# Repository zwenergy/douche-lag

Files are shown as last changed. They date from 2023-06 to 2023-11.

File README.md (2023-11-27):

# douche lag
A modular lag testing device.
Still very much in the works right now.

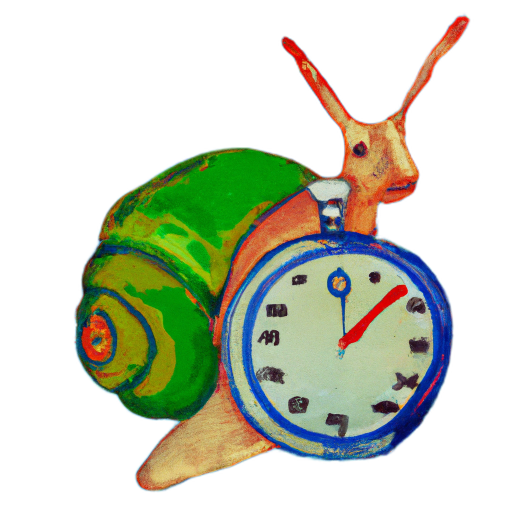
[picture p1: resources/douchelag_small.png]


*Amazingly cool and fancy logo of douche lag while keeping it SFW*

## Idea
The idea of douche lag is to have a simple and cheap, yet modular lag testing device to test the complete "lag chain" of a gaming system.
By "complete lag chain" I mean the time between button input and visual change on the screen.
Douche lag is doing that by emulating a button press and waiting for a visual change on screen.

The main idea is to be modular, that's why the project is split into 3 parts: The main board (containing the Raspberry Pi Pico and display), the "sense board" (which senses the visual change on the screen) and the "gamepad press emulation" (the part which actually emulates the button press).
The parts are connected using Mini DIN 6 cables/connectors.
The idea to keep it modular is to accomadate future updates.
Right now, it only supports displays which are back- or frontlit (since the sense board relies on a phototransistor) and gamepads which use a simple "commong ground switching" scheme.
To adapt this project to also non-lit displays, one could design a "sense board" with a color sensor.
Or more complex gamepads by designing a corresponding "gamepad daughter board".
Ideally, this potential future additions would not need a complete re-design, but only new daughter boards and a FW update.

## Test ROMs
Douche lag needs a program for each system to be tested which essentially toggles the display measurable by a button press.
Right now, there are ROMs for the following systems:
- GBA
- N64
- Genesis / Master Drive
- Saturn
- SNES
- NES

## Gamepad Modification
Right now, only gamepads which use a "common ground switching" scheme are supported (meaning a button press will cause the button input to be tied to ground).
For this, it's required to connect the ground connection of the "PAD" connector to the gamepad's ground, and "PAD1" to the button causing the display toggle.
This can be done in different ways:
- Permanently modify gamepad by adding a Mini DIN 6 connector
- Creating a "probing" cable with, e.g., multimeter probing heads on one side and a Mini DIN 6 connector on the other side
- Whatever you can think of

## BOM
### Main board
| **Reference** | **Part** | **Link** |
|---|---|---|
| U6 | Raspberry Pi Pico | [Digikey](https://www.digikey.com/en/products/detail/raspberry-pi/SC0915/13624793)|
| R1, R2 | 10k Ohm resistor 0805 | [LCSC](https://www.lcsc.com/product-detail/Chip-Resistor-Surface-Mount_UNI-ROYAL-Uniroyal-Elec-0805W8F1002T5E_C17414.html)|
| SW1, SW2 | Tactile switch | [LCSC](https://www.lcsc.com/product-detail/Tactile-Switches_BZCN-TSB008A2518A_C2888455.html)|
| PS1, PS2 | Mini DIN 6 connector | [LCSC](https://www.lcsc.com/product-detail/Circular-Connectors-Cable-Connectors_CONNFLY-Elec-DS1093-01-PN60_C77848.html)|
| PCB1 | 128x64 OLED display | [AliExpress](https://de.aliexpress.com/item/1005004242677199.html)|

**Make sure to get a display with the correct pinout order (VCC, GND, SCL, SDA) when looking from the top**

### Simple light sense board
| **Reference** | **Part** | **Link** |
|---|---|---|
| R1 | 1 kOhm resistor 1206 | [LCSC](https://www.lcsc.com/product-detail/Chip-Resistor-Surface-Mount_UNI-ROYAL-Uniroyal-Elec-1206W4F1001T5E_C4410.html)|
| R3 | 100 kOhm resistor 1206 | [LCSC](https://www.lcsc.com/product-detail/Chip-Resistor-Surface-Mount_UNI-ROYAL-Uniroyal-Elec-1206W4F1003T5E_C17900.html)|
| IR1 | Phototransistor 1206 | [LCSC](https://www.lcsc.com/product-detail/Phototransistors_Everlight-Elec-PT11-21C-L41-TR8_C16746.html)|
| Q1 | 2N7002 NMOS-FET SOT-23 | [LCSC](https://www.lcsc.com/product-detail/MOSFETs_Jiangsu-Changjing-Electronics-Technology-Co-Ltd-2N7002_C8545.html)|
| PS1 | Mini DIN 6 connector | [LCSC](https://www.lcsc.com/product-detail/Circular-Connectors-Cable-Connectors_CONNFLY-Elec-DS1093-01-PN60_C77848.html)|

## Usage
The main board simulates periodically a button press and meaures the time between this button press and the change on screen.
The button press is "emitted" via the Mini DIN 6 connector labelled "PAD".
Right now, effectively only two wires are used here to simulate a button press: ground and "PAD1".
This is enough for gamepads which use a "common ground switching scheme".

## Pinout Main Board to Gamepad Board
The following image shows a Mini DIN 6 connector (female, the one main board).

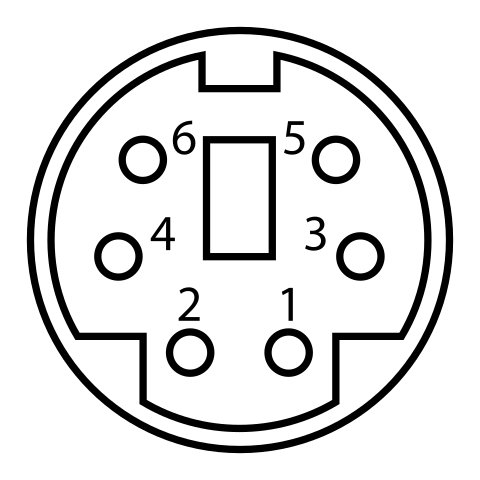
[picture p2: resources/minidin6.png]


| **Mini DIN 6 Pin** | **PAD Name** |
|---|---|
| 1 | Ground |
| 2 | PAD1 |
| 3 | PAD2|
| 4 | PAD3|
| 5 | PAD4|
| 6 | PAD5|

Right now, none of the PAD connection beside Ground and PAD1 connections are used.

## Disclaimer
**Use the files and/or schematics to build your own device at your own risk**.
This project works fine for me, but it's a simple hobby project, so there is no liability for errors in the schematics and/or board files.
**Use at your own risk**.

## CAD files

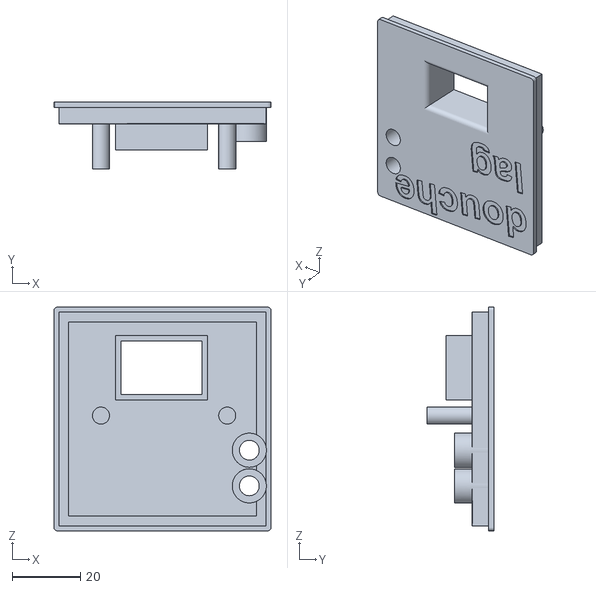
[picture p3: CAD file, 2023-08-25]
STL/main_case_top.stl
63.6 x 19.6 x 65.6

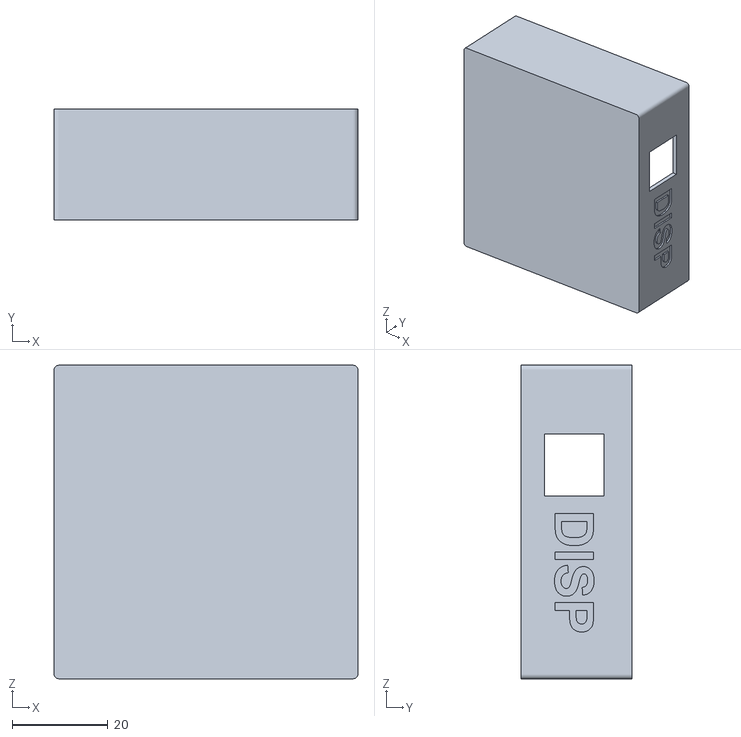
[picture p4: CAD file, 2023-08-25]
STL/main_case_body.stl
63.6 x 23.3 x 65.6

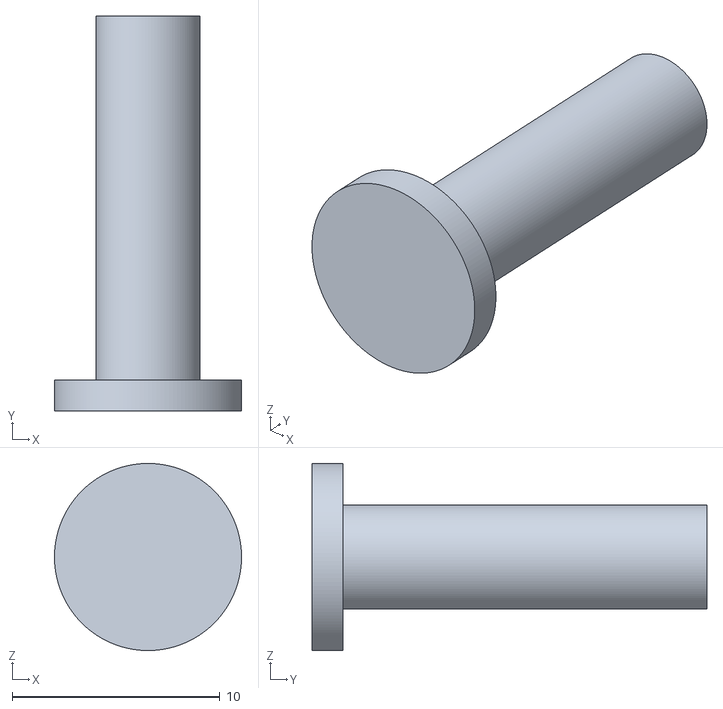
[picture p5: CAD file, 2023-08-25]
STL/main_case_button.stl
9.00 x 19.0 x 9.00

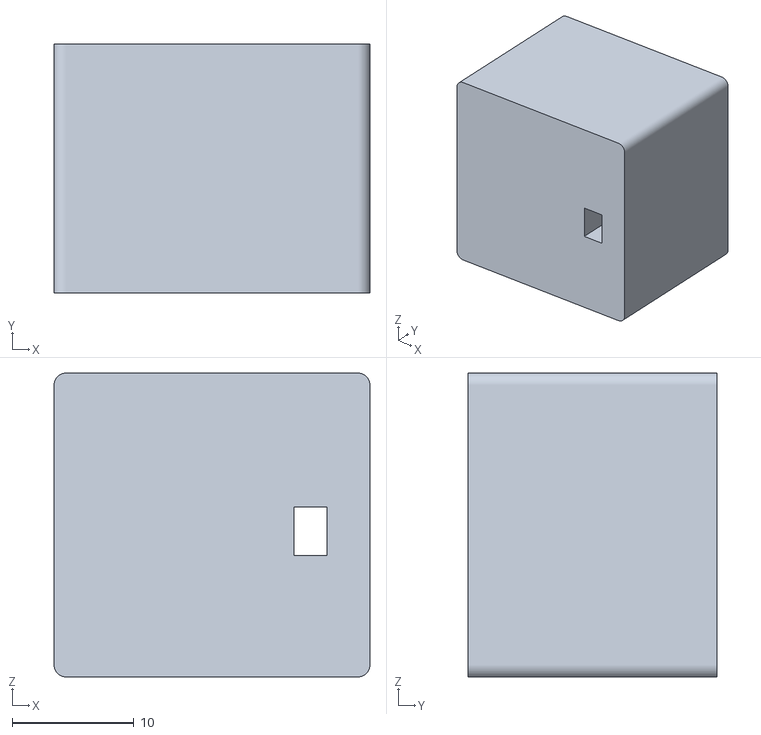
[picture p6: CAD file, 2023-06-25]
STL/senseboard_case_body.stl
26.0 x 20.5 x 25.0

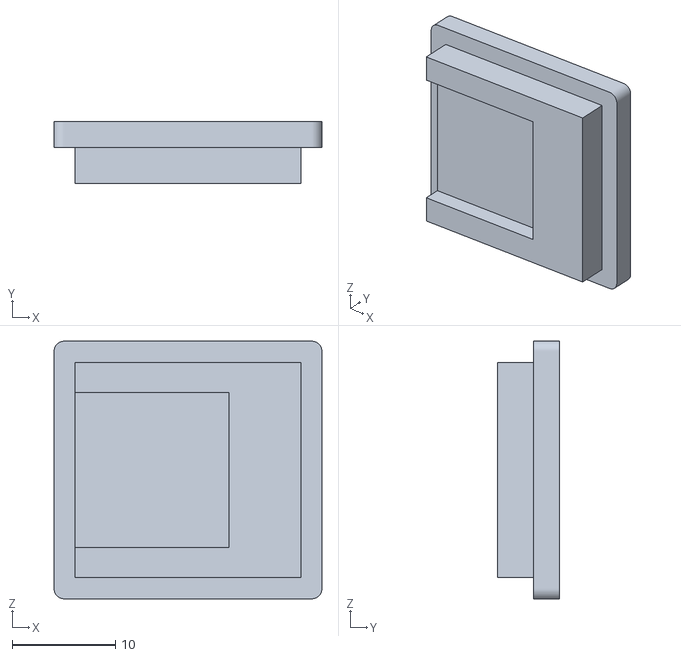
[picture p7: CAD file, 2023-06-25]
STL/senseboard_case_top.stl
26.0 x 6.00 x 25.0

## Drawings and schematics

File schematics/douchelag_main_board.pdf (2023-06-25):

A | A

1

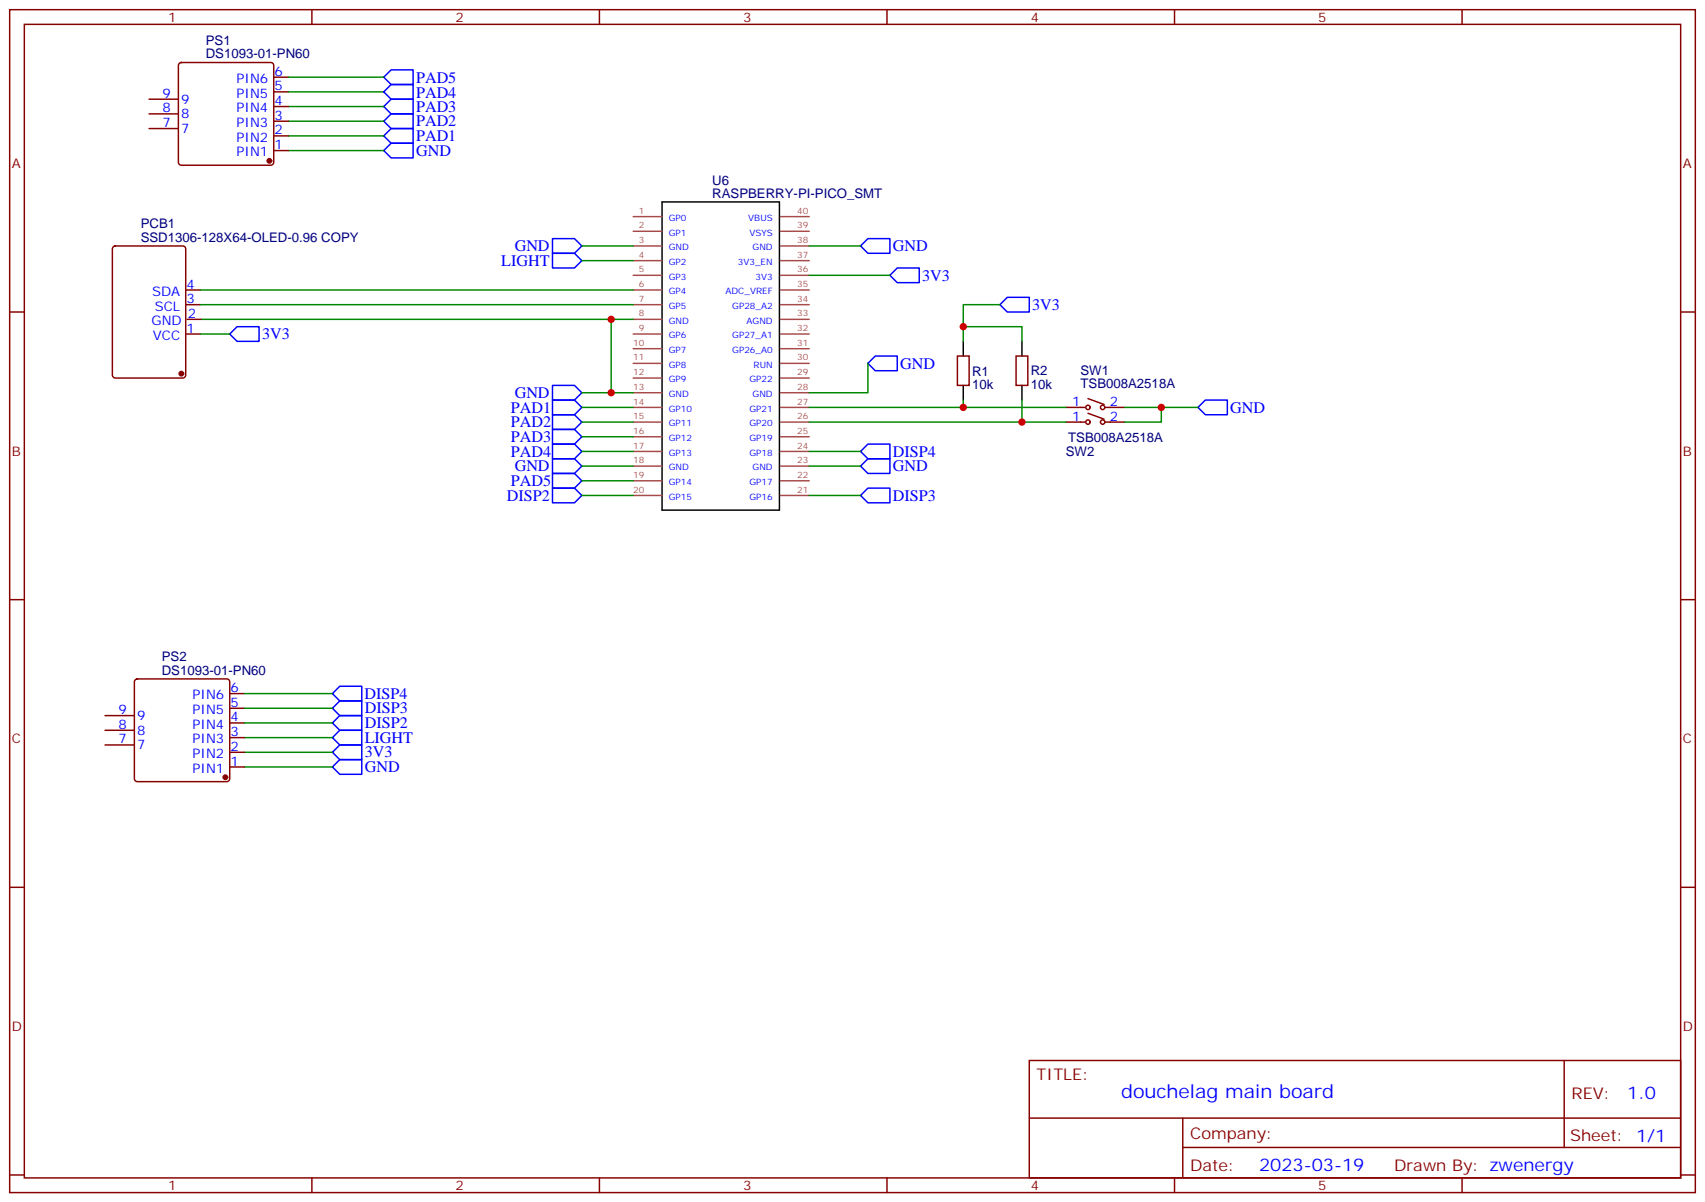
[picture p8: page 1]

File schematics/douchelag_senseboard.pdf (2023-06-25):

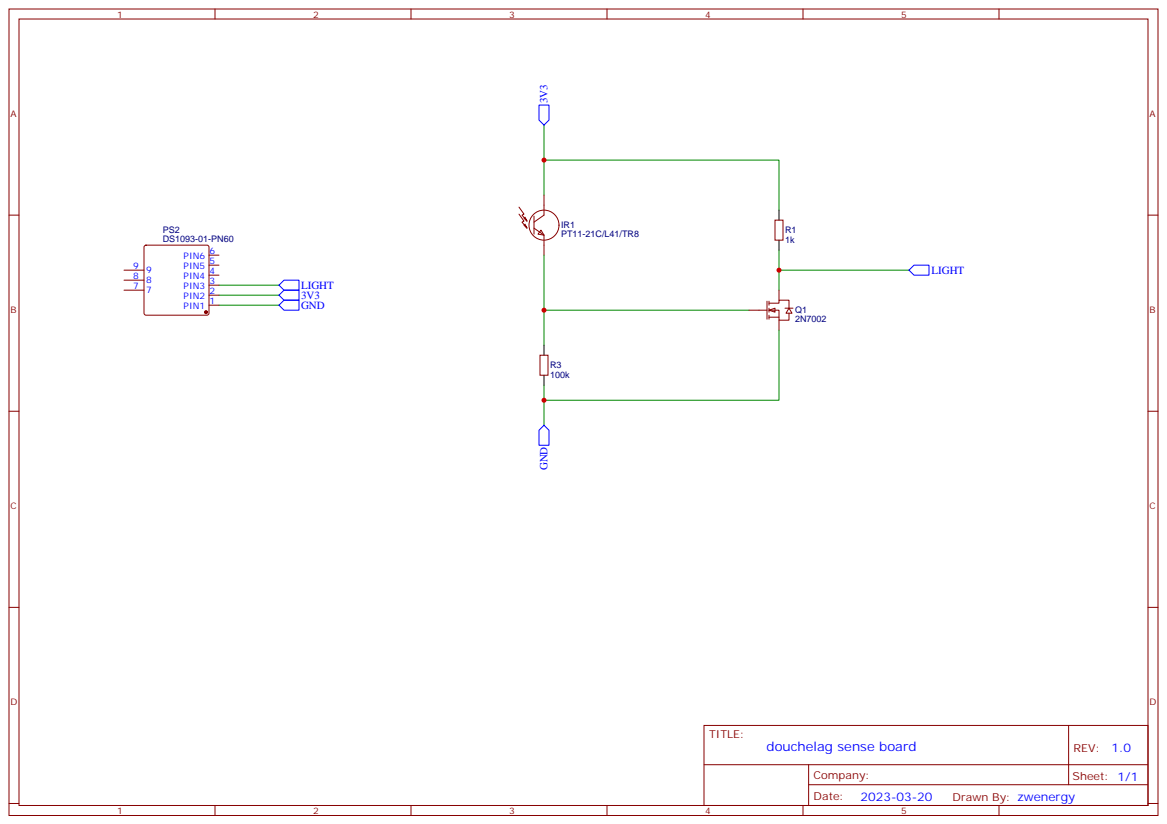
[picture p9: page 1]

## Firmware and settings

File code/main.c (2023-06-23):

#include <stdio.h>
#include <stdint.h>
#include <string.h>
#include "pico/stdlib.h"
#include "hardware/i2c.h"
#include <time.h>

#include "ssd1306.h"

#define I2C_SDA 4
#define I2C_CLK 5

#define LIGHTSENSE 2
#define PAD1 10
#define PAD2 11
#define PAD3 12
#define BTN1 21
#define BTN2 20

#define SCREENUS 500000
#define TOGGLEUS 60000
#define MAXSCREENDELAYUS SCREENUS / 2

// Number of readings per batch
#define BATCHSIZE 20

void setupGPIO() {
  stdio_init_all();
  
  // Display pins
  i2c_init(i2c0, 400000);
  gpio_set_function(I2C_SDA, GPIO_FUNC_I2C);
  gpio_set_function(I2C_CLK, GPIO_FUNC_I2C);
  gpio_pull_up(I2C_SDA);
  gpio_pull_up(I2C_CLK);
  
  // Light pin
  gpio_init(LIGHTSENSE);
  gpio_set_dir(LIGHTSENSE, GPIO_IN);
  //gpio_pull_up( LIGHTSENSE );
  
  // Buttons.
  gpio_init(BTN1);
  gpio_set_dir(BTN1, GPIO_IN);
  gpio_init(BTN2);
  gpio_set_dir(BTN2, GPIO_IN);
  
  // Pad, for the first set to input.
  gpio_init(PAD1);
  gpio_set_dir(PAD1, GPIO_IN);
  gpio_init(PAD2);
  gpio_set_dir(PAD2, GPIO_IN);
  gpio_init(PAD3);
  gpio_set_dir(PAD3, GPIO_IN);
  
}

int main() {
  stdio_init_all();
  setupGPIO();
  
  printf( "Starting\n" );
  
  // Set up display.
  ssd1306_t disp;
  disp.external_vcc = false;
  ssd1306_init( &disp, 128, 64, 0x3C, i2c0 );
  ssd1306_clear( &disp );
  
  // For GBA, set the output register value to low.
  gpio_put( PAD1, 0 );
  //gpio_pull_up( PAD1 );
  
  // Doing the actual measurement
  unsigned curMeasurement = 0;
  unsigned totalMeasurements = 0;
  unsigned lastSensorVal = 0;
  
  // Average val for measurements
  unsigned lagVals[ BATCHSIZE ];
  for ( int i = 0; i < BATCHSIZE; ++i ) {
    lagVals[ i ] = 0;
  }
  
  unsigned registeredChange = 1;
  
  uint64_t buttonPressTime = time_us_64();
  unsigned toggling = 0;
  
  unsigned init = 1;
  // We do not know initially, what color is showing on the screen.
  // We just assume it's black (curScreen = 0). If it's wrong, we change
  // the internal state.
  unsigned curScreen = 0; // black
    
  while ( 1 ) {
    // Get the current light value.
    // Light val == 1 is black, val == 0 is white
    unsigned lightVal = gpio_get( LIGHTSENSE );
    uint64_t curTime = time_us_64();
    
    // Check if a change was detected.
    if ( lightVal != lastSensorVal ) {      
      if ( !registeredChange ) {
        // Only interested in black to white.
        if (lastSensorVal == 1 && lightVal == 0 ) {
          uint32_t lag = (uint32_t) ( curTime - buttonPressTime );
          printf( "Got change!\n" );
          
          lagVals[ curMeasurement ] = lag;
          ++curMeasurement;
          ++totalMeasurements;
          
          if ( curMeasurement >= BATCHSIZE ) {
            curMeasurement = 0;
          }
          
          unsigned minLag = -1;
          unsigned maxLag = 0;
          unsigned avgLag = 0;
          unsigned cnt = 0;
          
          for ( int i = 0; i < BATCHSIZE; ++i ) {
            if ( i >= totalMeasurements ) {
              break;
            }
            
            unsigned curVal = lagVals[ i ];            
            avgLag += curVal;
            
            if ( curVal > maxLag ) {
              maxLag = curVal;
            }
            
            if ( curVal < minLag ) {
              minLag = curVal;
            }
            
            ++cnt;
          }
          
          avgLag = avgLag / cnt;
          
          float avgLag_f = (float) avgLag / 1000.0f;
          float minLag_f = (float) minLag / 1000.0f;
          float maxLag_f = (float) maxLag / 1000.0f;
          
          char textout[100];
          ssd1306_clear( &disp );
          sprintf( textout, "Avg Lag: %f ms", avgLag_f );
          ssd1306_draw_string( &disp, 0, 0, 1, textout );
          sprintf( textout, "Max Lag: %f ms", maxLag_f );
          ssd1306_draw_string( &disp, 0, 16, 1, textout );
          sprintf( textout, "Min Lag: %f ms", minLag_f );
          ssd1306_draw_string( &disp, 0, 32, 1, textout );
          ssd1306_show(&disp);
        }
        
      } else {
        // During white screen, the PWM of many screens cause it to
        // register also black here.
        // Yet, make sure that we did not just switch to a black screen
        // and are seeing a delay.
        if ( curTime - buttonPressTime > MAXSCREENDELAYUS ) {
          curScreen = 1;
        }
      }

      registeredChange = 1;
    }
    
    // Toggle screen?
    if ( curTime - buttonPressTime > SCREENUS ) {
      gpio_set_dir( PAD1, GPIO_OUT );
      buttonPressTime = time_us_64();
      toggling = 1;
      curScreen = !curScreen;
      
      // New screen is white?
      if ( curScreen ) {
        registeredChange = 0;
      }
      
    } else if ( curTime - buttonPressTime > TOGGLEUS && toggling ) {
      // Release button?
      gpio_set_dir( PAD1, GPIO_IN );
      toggling = 0;
    }
    
    lastSensorVal = lightVal;
  }
  
}

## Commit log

2023-06-25 Added more stuff.
    [senseboard_case_body.stl, senseboard_case_top.stl]
2023-06-25 Add Mini DIN 6 connector.
2023-08-25 Added STL files for the main case.
    [main_case_body.stl, main_case_button.stl, main_case_top.stl]
